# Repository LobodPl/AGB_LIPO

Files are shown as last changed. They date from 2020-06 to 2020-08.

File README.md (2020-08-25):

# README AGB_LIPO from makhowastaken

LiPo adapter for Game Boy Advance.

* Uses these battery terminals: https://www.aliexpress.com/item/32946601230.html
* a standard TP4056 module (Micro USB or USB C): https://www.aliexpress.com/item/32649780468.html
* and pretty much whatever diode you can get your hands on: https://www.aliexpress.com/item/32664545131.html

I got my boards in and had to make some alterations to get them to fit better. I'm still waiting on the terminals so I'll add a youtube video for instruction when I get everything in.
# My Project README

## Order at OSHPARK: https://oshpark.com/shared_projects/AJPIjHIz

## Front:
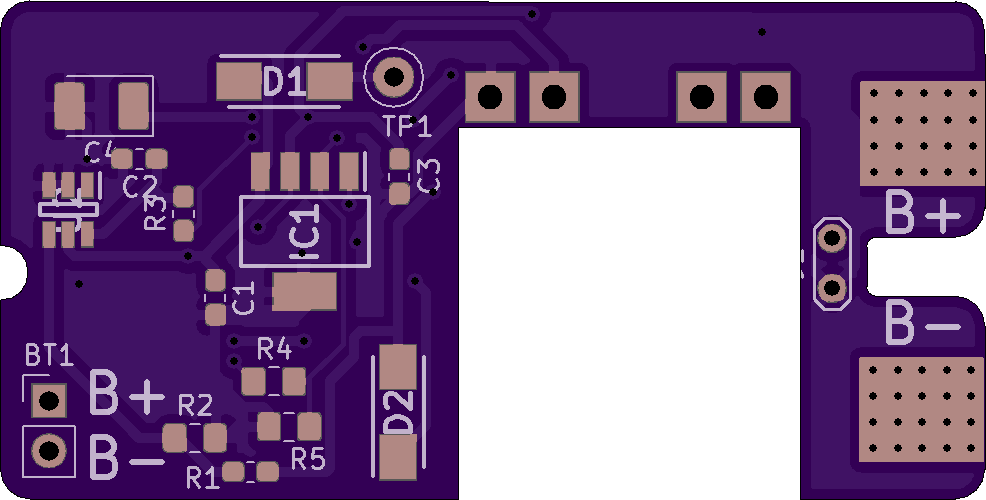
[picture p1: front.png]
front


* Solder TP1 to VIN+ of TP4056
## Back:
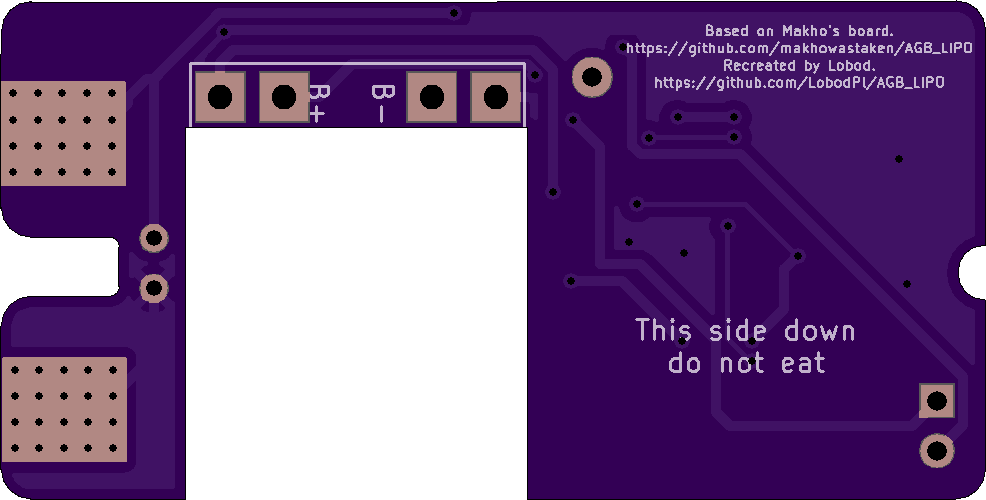
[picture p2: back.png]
back


# Symbols
* U1 - TP4056(Have to be soldered UpsideDown)
  https://aliexpress.com/item/32649780468.html (0,41$)
* U2 - TPS3700DDCR (Texas Intruments)
  https://mouser.com/ProductDetail/Texas-Instruments/TPS3700DDCR?qs=mNuCSSXMdBz5rDLbdTsfrQ%3D%3D (1,79$)
* IC1 - LP38693MP-ADJ (Texas Intruments)
  https://mouser.com/ProductDetail/Texas-Instruments/LP38693MP-ADJ-NOPB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 (1,45$)
* D1,D2 - SS14 Schottky Diode (or silmilar schottky diode)
  https://mouser.com/ProductDetail/ON-Semiconductor-Fairchild/SS14?qs=mVVXn4M53U%252BvrBaFv5vr4w%3D%3D (0,76$)
* C1,C2,C3 - 10u CERAMIC(0603)
  https://mouser.com/ProductDetail/Taiyo-Yuden/JMK107ABJ106KAHT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 (1$)
* C4 - 220u TANTALUM(KEMET-B)
  https://mouser.com/ProductDetail/Vishay-Sprague/TR3B106K010C1000?qs=l4Gc20tDgJLwalMJRLTcCw%3D%3D (1,08$)
* R1 - 470K(0603)
  https://mouser.com/ProductDetail/Panasonic/ERJ-UP3J474V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 (0,18$)
* R2 - 62K(0805)
  https://mouser.com/ProductDetail/Panasonic/ERJ-6RBD6202V?qs=sGAEpiMZZMtlubZbdhIBIAseYdsNAjdpz1c9XO5OoSg%3D (0,14$)
* R3 - 1M(0603)
  https://mouser.com/ProductDetail/Panasonic/ERJ-UP3D1004V?qs=sGAEpiMZZMtlubZbdhIBINZyO39%252BOXIfwSlLGtGqBNU%3D (0,35$)
* R4,R5 - 240K(0805)
  https://mouser.com/ProductDetail/Panasonic/ERJ-PB6B2403V?qs=sGAEpiMZZMtlubZbdhIBIMNI7sOfyRuJn5D0R%252BVWI38%3D (0,72$)
* BT1 - 103048 LiPo Cell
  https://pl.aliexpress.com/item/33000132990.html (3$)
# Cost

  PCB manufacturing costs: **2$** on JLCPCB or **9$** on OSHPARK.
  
  This project with **JLCPCB** will cost you ~13$.
  
  With **OSHPARK** you will pay ~20$.

# My Changes

* Load Sharing.
* Voltage Regulation to 3V.
* GBA Low Battery Light trigered at LiPo 3,4V.

# CHANGELOG
## >28.04.2020
* Base concept.

## 28.04.2020
* Added 3.3V Regulator.

## 29.04.2020
* Fixed Regulator capacitors.

## 01.05.2020
* Full circuit redesign.

## 01.06.2020
* One more full circuit redesign.

## 17.06.2020
* Finall release. PCB is now working corectly.

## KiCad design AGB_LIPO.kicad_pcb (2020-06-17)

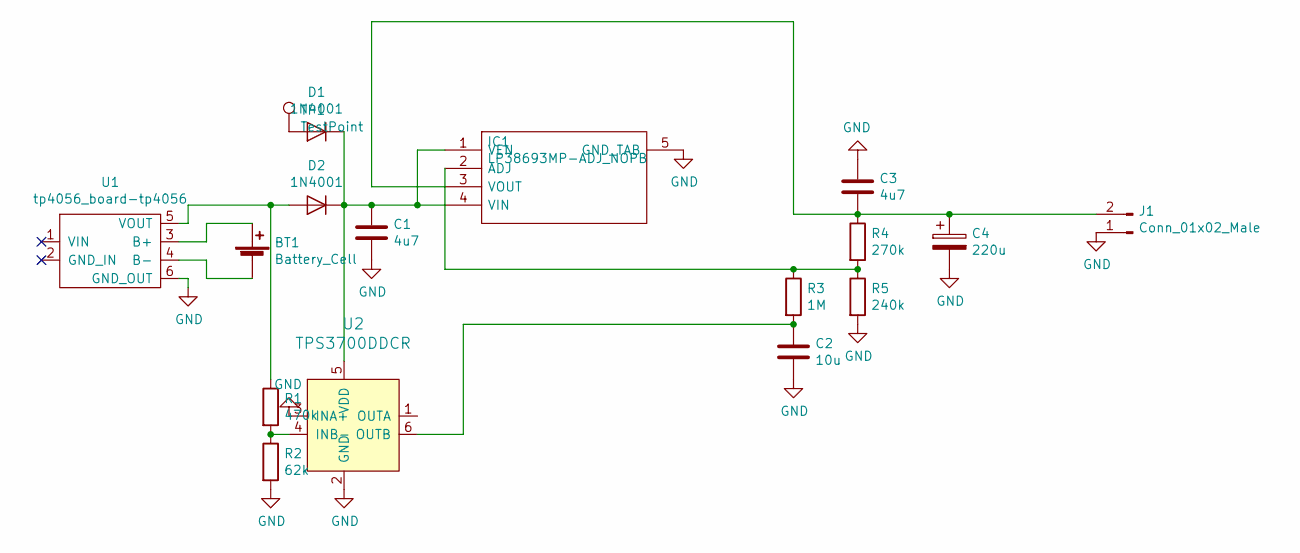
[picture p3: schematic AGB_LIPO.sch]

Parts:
BT1: Battery_Cell; PinHeader_1x02_P2.54mm_Vertical
C1, C3: 4u7; C_0603_1608Metric_Pad1.05x0.95mm_HandSolder
C2: 10u; C_0603_1608Metric_Pad1.05x0.95mm_HandSolder
C4: 220u; CP_EIA-3528-21_Kemet-B_Pad1.50x2.35mm_HandSolder
D1, D2: 1N4001; DIOM5626X245N
IC1: LP38693MP-ADJ_NOPB; SOT150P700X180-5N; Manufacturer_Part_Number LP38693MP-ADJ/NOPB; Mouser Part Number 926-LP38693MPADJNOPB
J1: Conn_01x02_Male; TestPoint_2Pads_Pitch2.54mm_Drill0.8mm
R1: 470k; R_0603_1608Metric_Pad1.05x0.95mm_HandSolder
R2: 62k; R_0805_2012Metric_Pad1.15x1.40mm_HandSolder
R3: 1M; R_0603_1608Metric_Pad1.05x0.95mm_HandSolder
R4: 270k; R_0805_2012Metric_Pad1.15x1.40mm_HandSolder
R5: 240k; R_0805_2012Metric_Pad1.15x1.40mm_HandSolder
TP1: TestPoint; TestPoint_Loop_D1.80mm_Drill1.0mm_Beaded
U1: tp4056_board-tp4056; 4056E_LiIon_loader
U2: TPS3700DDCR; SOT98P280X110-6N; MPN TPS3700DDCR; Digi-Key_PN 296-30395-1-ND

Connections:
GND: C1.2, C2.2, C3.1, C4.2, IC1.5 (GND_TAB), J1.1, R2.2, R5.2, U1.6 (GND_OUT), U2.2 (GND), U2.3 (INA+)
unnamed: BT1.1 (+), U1.3 (B+)
unnamed: BT1.2 (-), U1.4 (B-)
unnamed: C1.1, D1.1 (K), D2.1 (K), IC1.1 (VEN), IC1.4 (VIN), U2.5 (VDD)
unnamed: C2.1, R3.2, U2.6 (OUTB)
unnamed: C3.2, C4.1, IC1.3 (VOUT), J1.2, R4.1
unnamed: D1.2 (A), TP1.1
unnamed: D2.2 (A), R1.1, U1.5 (VOUT)
unnamed: IC1.2 (ADJ), R3.1, R4.2, R5.1
unnamed: R1.2, R2.1, U2.4 (INB-)

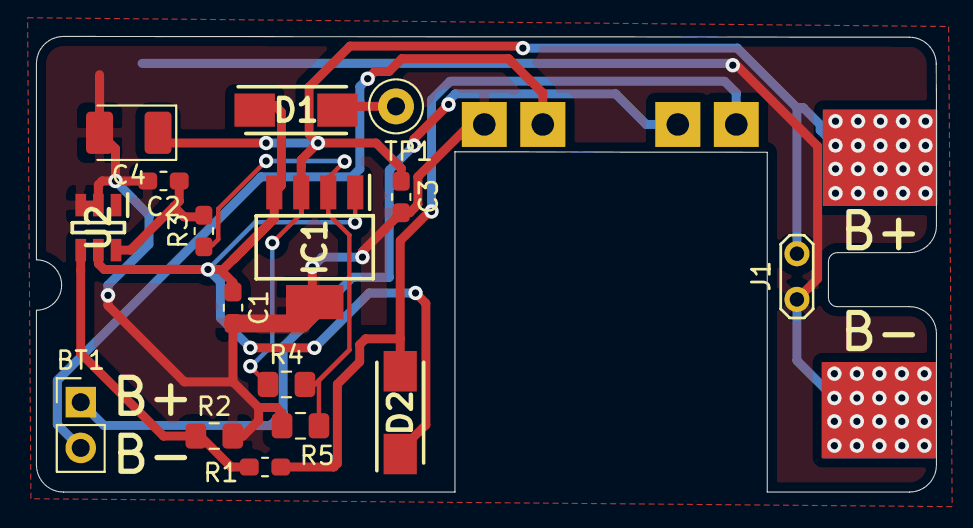
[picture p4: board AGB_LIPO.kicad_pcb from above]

Board: 2 copper layers, 50.0 x 25.3 mm, 17 parts (1 on the bottom side), 10 nets.

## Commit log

2020-04-26 Load Sharing and Voltage stabilizer
    [AGB_LIPO-B_Cu.gbl, AGB_LIPO-B_Mask.gbs, AGB_LIPO-B_SilkS.gbo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]
2020-04-26 Board updated
    [AGB_LIPO-B_Cu.gbl, AGB_LIPO-B_Mask.gbs, AGB_LIPO-B_SilkS.gbo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]
2020-04-29 29/04 Update
    [AGB_LIPO-B_Cu.gbl, AGB_LIPO-B_Mask.gbs, AGB_LIPO-B_SilkS.gbo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]
2020-04-29 29/04 Updated photos
    [AGB_LIPO-B_Cu.gbl, AGB_LIPO-B_Mask.gbs, AGB_LIPO-B_SilkS.gbo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]
2020-04-29 29/04 Symbol fix
    [AGB_LIPO.kicad_pcb, AGB_LIPO.sch]
2020-05-01 Full Circuit redesign
    [AGB_LIPO-B_Cu.gbl, AGB_LIPO-B_Mask.gbs, AGB_LIPO-B_SilkS.gbo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]
2020-05-01 01/05 Full Circuit redesign README FIX
2020-06-17 17.06 UPDATE
    [AGB_LIPO-B_Cu.gbl, AGB_LIPO-B_Mask.gbs, AGB_LIPO-B_SilkS.gbo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]
